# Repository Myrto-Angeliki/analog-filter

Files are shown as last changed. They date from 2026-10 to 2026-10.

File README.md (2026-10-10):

# Analog Front-End (AFE) Active Low-Pass Filter Module

A custom 2-layer printed circuit board (PCB) designed in KiCad for sensor signal conditioning in embedded hardware systems. This module combines a low-noise $3.3\text{V}$ Low-Dropout (LDO) power regulator with a 2nd-order active Sallen-Key low-pass filter ($f_c \approx 1.06\text{ kHz}$) and a unity-gain buffer stage to attenuate high-frequency noise prior to Analog-to-Digital Converter (ADC) sampling.

---

## Technical Specifications

* **Input Voltage ($V_{CC}$):** $5.0\text{V DC}$ nominal
* **Regulated Rail ($V_{DD}$):** $3.3\text{V DC}$ (AP2112K-3.3 LDO, up to $600\text{mA}$)
* **Filter Topology:** 2nd-Order Sallen-Key Low-Pass Filter + Output Voltage Follower Buffer
* **Characteristic Frequency ($f_c$):** $1.061\text{ kHz}$ ($-6\text{ dB}$)
* **Roll-off Rate:** $-40\text{ dB/decade}$
* **Active Components:** 
[MCP6002 Dual Rail-to-Rail CMOS Operational Amplifier (SOIC-8)](https://ww1.microchip.com/downloads/aemDocuments/documents/MSLD/ProductDocuments/DataSheets/MCP6001-1R-1U-2-4-1-MHz-Low-Power-Op-Amp-DS20001733L.pdf) , 
[AP2112K-3.3 LDO (SOT-23-5/SOT-25)](https://gr.mouser.com/datasheet/3/175/1/AP2112.pdf)
* **PCB Form Factor:** 2-Layer, $30\text{ mm} \times 40\text{ mm}$, hybrid SMT ICs with through-hole passives for rapid benchtop prototype assembly.

---

## Circuit Architecture & Calculations

### 1. Power Management & Decoupling
* **LDO Regulator:** AP2112K-3.3 steps down $5\text{V}$ $V_{CC}$ to a quiet $3.3\text{V}$ analog power rail.
* **Input/Output Capacitors:** $1\ \mu\text{F}$ MLCC on $V_{IN}$ and a $2.2\ \mu\text{F}$ MLCC on $V_{OUT}$. The $2.2\ \mu\text{F}$ value was selected over the $1\ \mu\text{F}$ minimum datasheet rating to account for ceramic DC-bias capacitance derating at $3.3\text{V}$ operating potential.
* **Local Decoupling:** A $100\text{ nF}$ ceramic capacitor is placed directly adjacent to the MCP6002 op-amp $V_{DD}$ pin (Pin 8) to mitigate high-frequency supply ripple.

### Sallen-Key Low-Pass Filter

The characteristic frequency ($f_0$) for the selected equal-component configuration ($R_1 = R_2 = 10\text{ k}\Omega$, $C_1 = C_2 = 15\text{ nF}$) is:

$$f_0 = \frac{1}{2\pi \sqrt{R_1 R_2 C_1 C_2}} \approx 1,061\text{ Hz}$$

Because $C_1 = C_2$, $R1 = R2$ and because tha operational amplifier is configured as a unity gain buffer (A = 1), the filter operates with $Q = 0.5$ (critically damped response):
* **Characteristic Frequency ($f_0$):** $1.061\text{ kHz}$ ($-6\text{ dB}$ attenuation)
* **Half-Power Cutoff Frequency ($f_{-3\text{dB}}$):** $\approx 683\text{ Hz}$ ($-3\text{ dB}$ attenuation)

### 3. Output Buffer
Op-Amp Channel B of MCP6002 is configured as a unity-gain voltage follower (connecting `OUTB` Pin 7 to `INB-` Pin 6). This presents a high input impedance to the filter stage and a low output drive impedance to downstream microcontrollers, eliminating loading effects on the filter's frequency response.

---

## LTspice Simulation

Prior to layout, the Sallen-Key low-pass filter was validated in LTspice using small-signal AC frequency analysis.

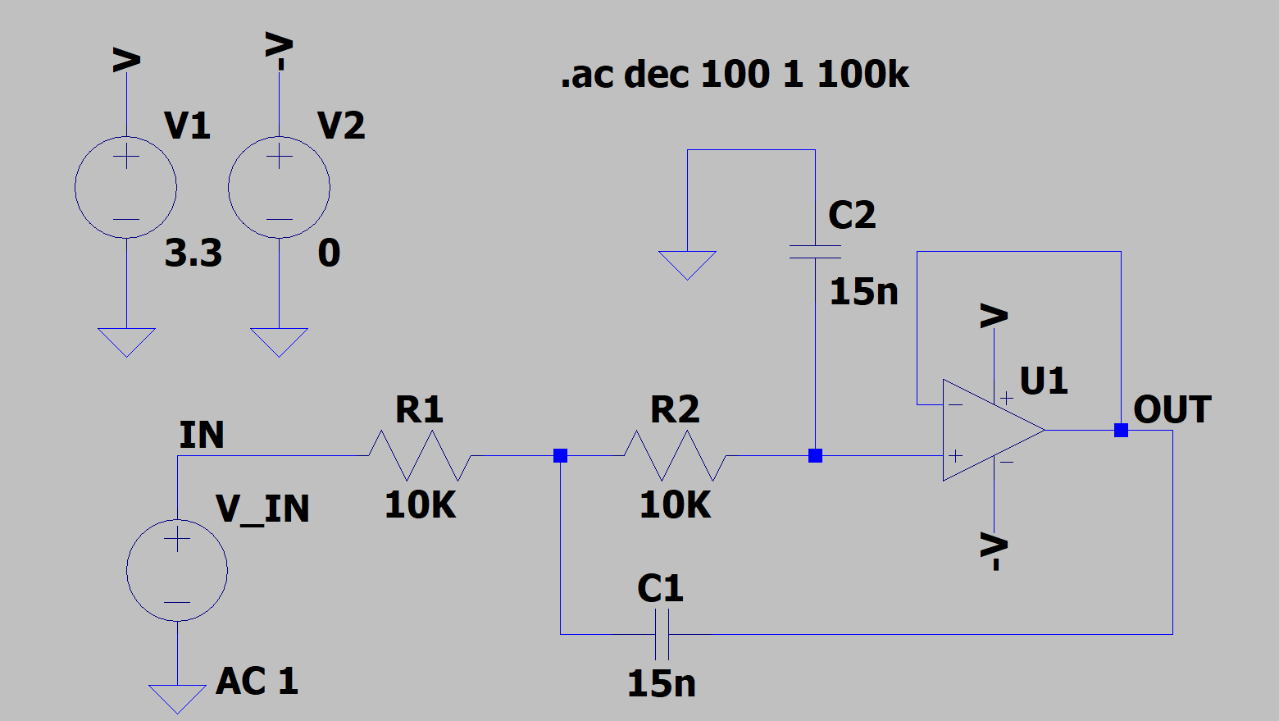
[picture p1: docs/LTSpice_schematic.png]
LTSpice_schematic


<br />

* **Simulation Directive:** `.ac dec 100 1 100k`
* **Passband Gain:** $0\text{ dB}$ up to $100\text{ Hz}$
* **$-6\text{ dB}$ frequency:** Verified at $\approx 1.06\text{ kHz}$
* **$-3\text{ dB}$ frequency:** Verified at $\approx 683\text{ Hz}$
* **Stopband Attenuation:** Confirmed $-40\text{ dB/decade}$ attenuation slope above cutoff frequency.

<table align="center">
    <thead>
        <tr>
            <th scope="col">Frequency at -3 dB</th>
            <th scope="col">Frequency at -6 dB</th>
            <th scope="col">Attenuation slope above cutoff frequency</th>
        </tr>
    </thead>
    <tbody> 
        <tr>
            <td>
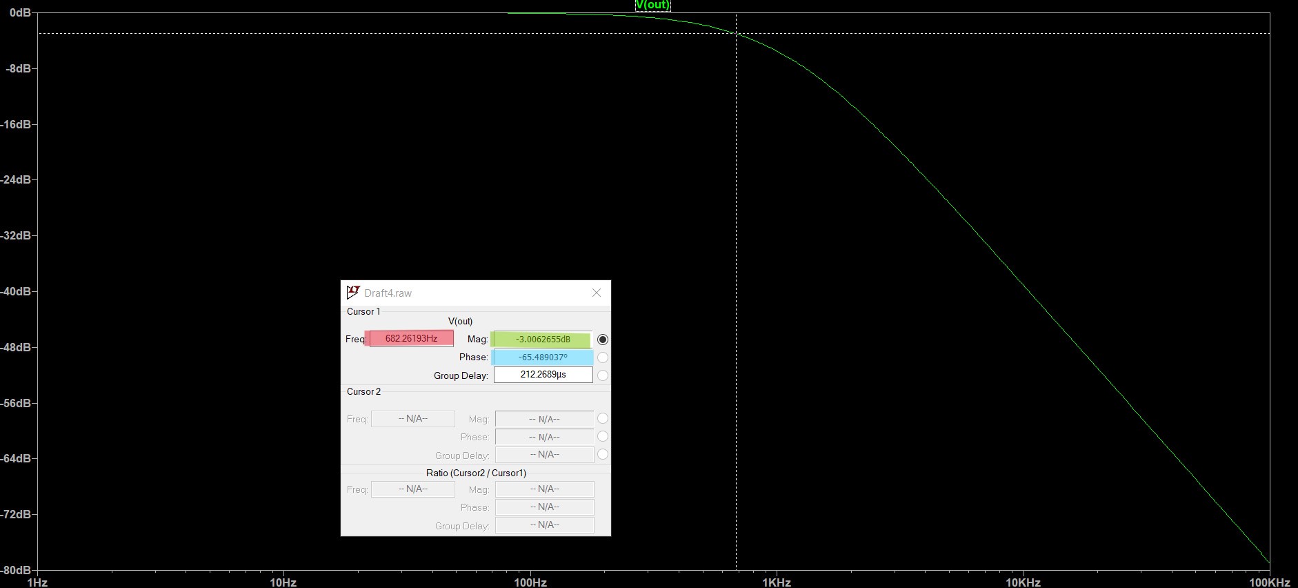
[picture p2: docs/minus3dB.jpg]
frequency-at-minus3dB
                 
            </td>
            <td>
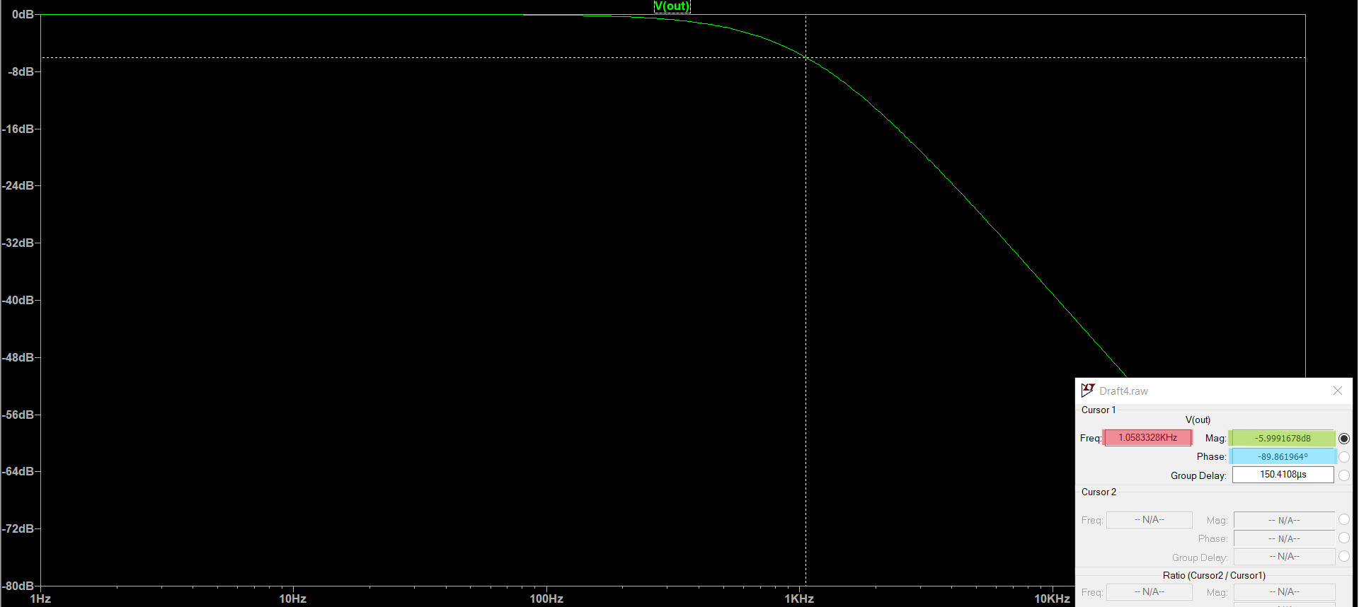
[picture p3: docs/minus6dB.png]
frequency-at-minus6dB
                
            </td>
            <td>
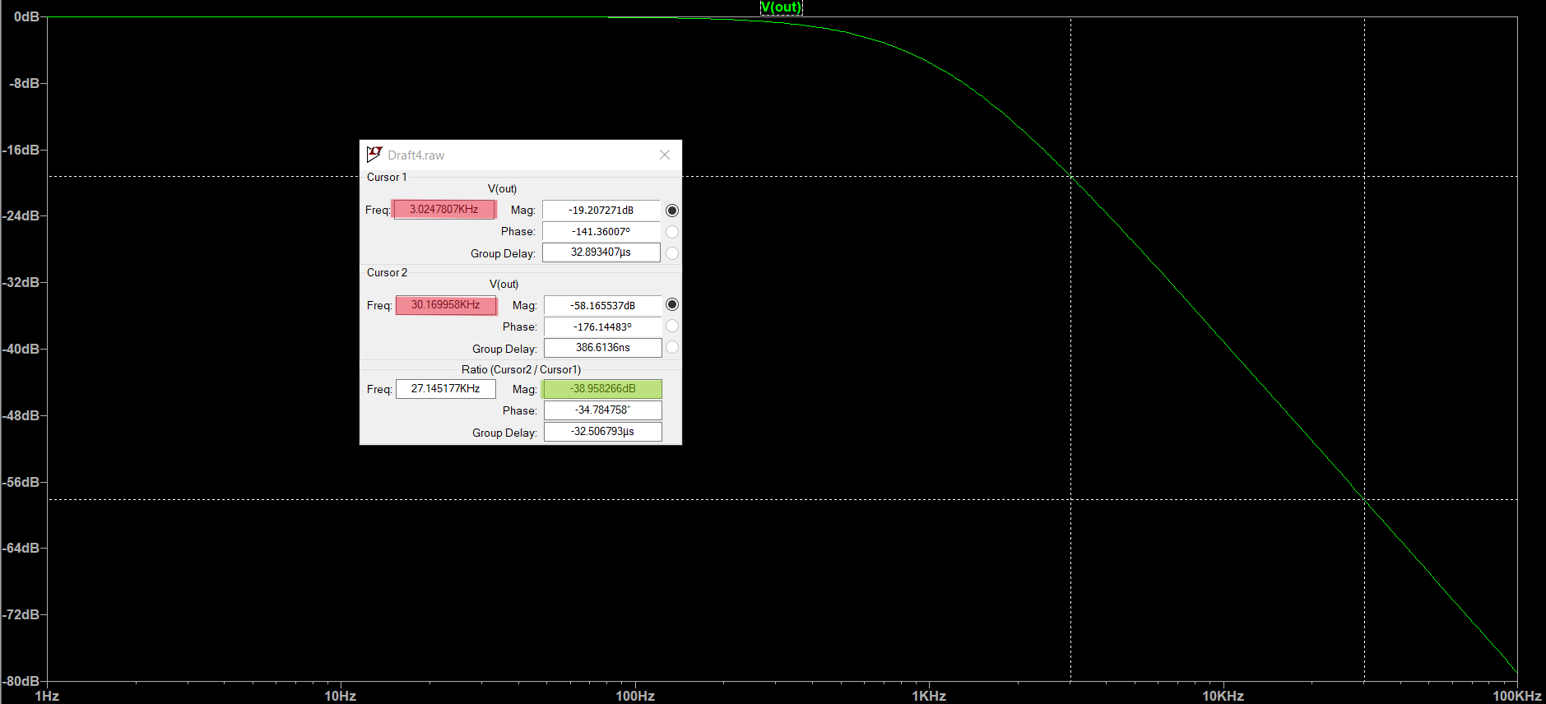
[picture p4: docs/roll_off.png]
attenuation-slope
                
            </td>
        </tr> 
    </tbody> 
</table>
<p align="center">
  <em>Measurings on the Bode plot output for the V(out) trace (Gain = 1).</em>
</p>

<br />

---

## Board Pinout & Interface

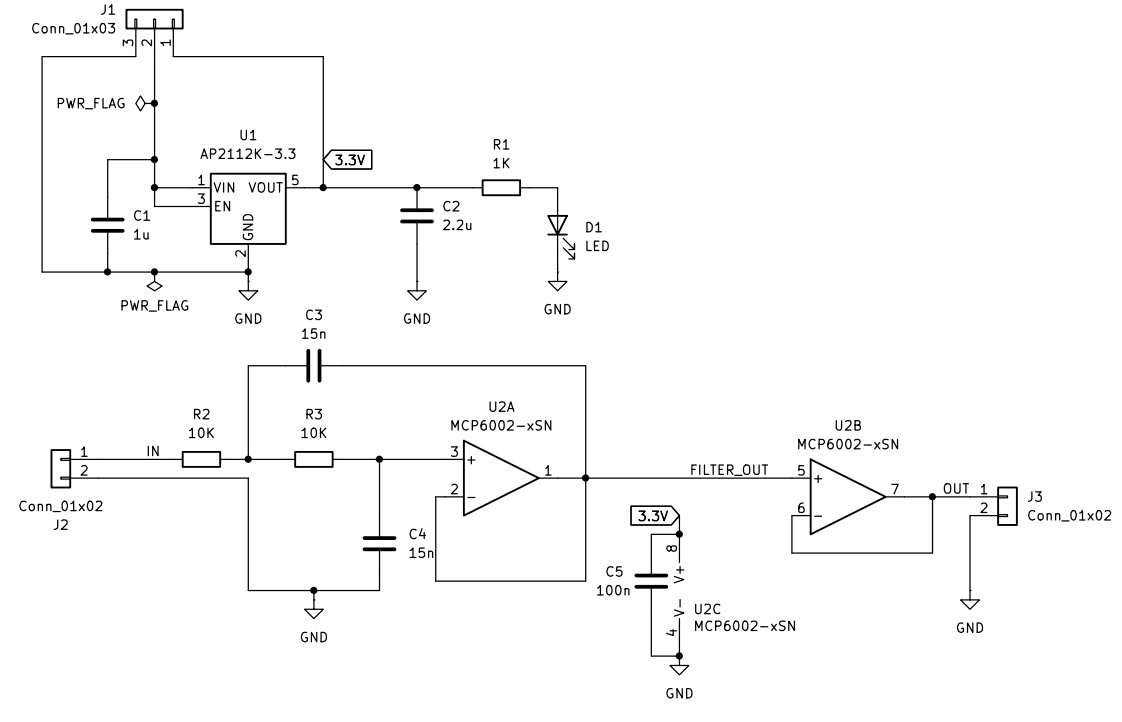
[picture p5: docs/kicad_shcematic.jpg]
KiCad_schematic


| Header | Pin | Name | Type | Description |
| :--- | :--- | :--- | :--- | :--- |
| **Power (J1)** | 1 | `3.3V` | Power | $+3.3\text{V}$ Regulated Output Rail |
| | 2 | `VCC` | Power | $+5.0\text{V}$ Unregulated Power Input |
| | 3 | `GND` | Power | Common System Ground Plane |
| **Input (J2)** | 1 | `IN` | Analog Input | Raw Signal Input from Sensor |
| | 2 | `GND` | Power | Signal Ground |
| **Output (J3)**| 1 | `OUT` | Analog Output| Conditioned & Buffered Signal to ADC |
| | 2 | `GND` | Power | Signal Ground |

---

## PCB Layout Considerations

<table align="center">
    <thead>
        <tr>
            <th scope="col">PCB Front 3D View with Visible Components</th>
            <th scope="col">PCB Back 3D View with Visible Components</th>
        </tr>
    </thead>
    <tbody> 
        <tr>
            <!-- <th scope="row"></th> -->
            <td>
                <a href="docs\analog_filter_modules_front_models.png"> 
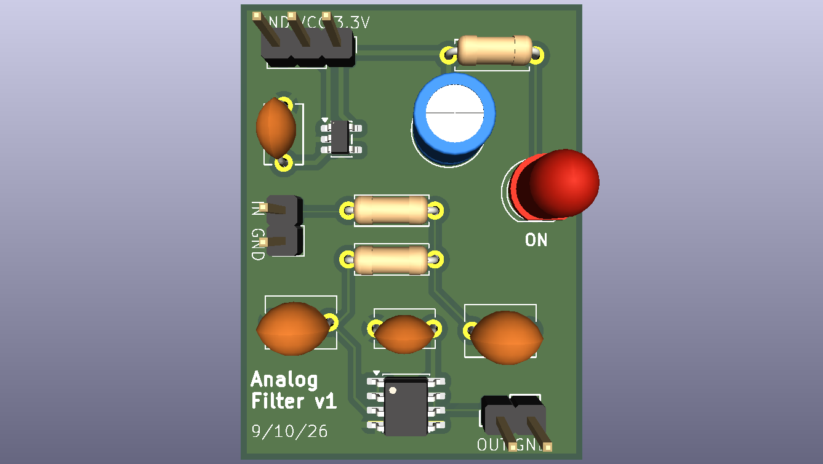
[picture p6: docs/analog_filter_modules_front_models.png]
pcd-front-with-modules
                     
                </a> 
            </td>
            <td>
                <a href="docs\analog_filter_modules_back_models.png"> 
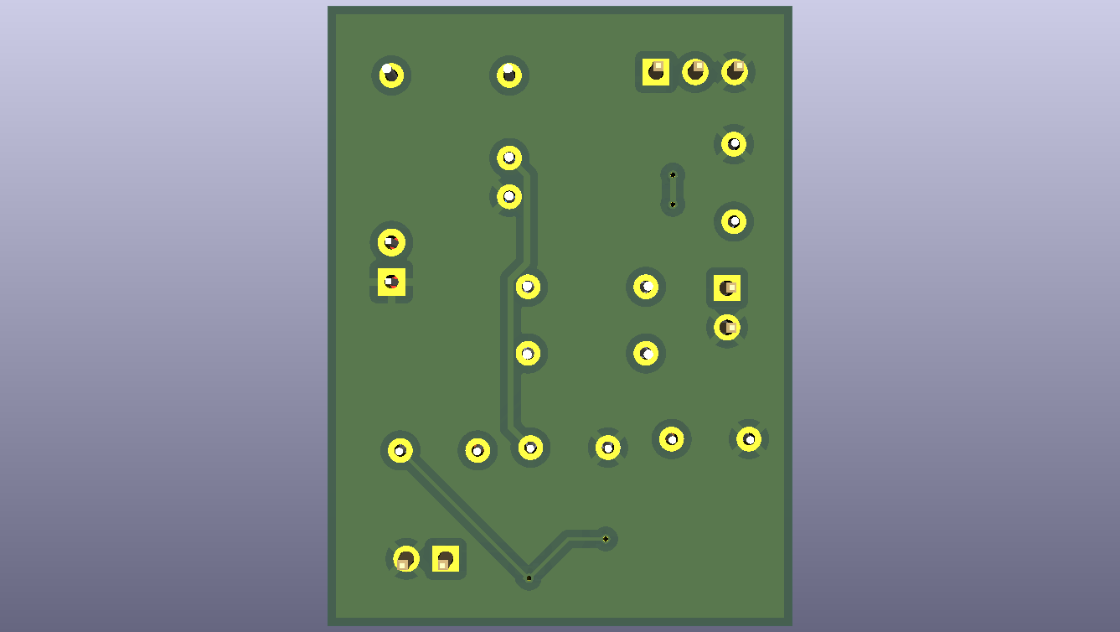
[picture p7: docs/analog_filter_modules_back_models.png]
pcd-back-with-modules
                      
                </a> 
            </td>
        </tr> 
        <tr>
            <th scope="col">PCB Front 3D View</th>
            <th scope="col">PCB Back 3D View</th>
        </tr>
        <tr>
            <td>
                <a href="docs\analog_filter_modules_front.png"> 
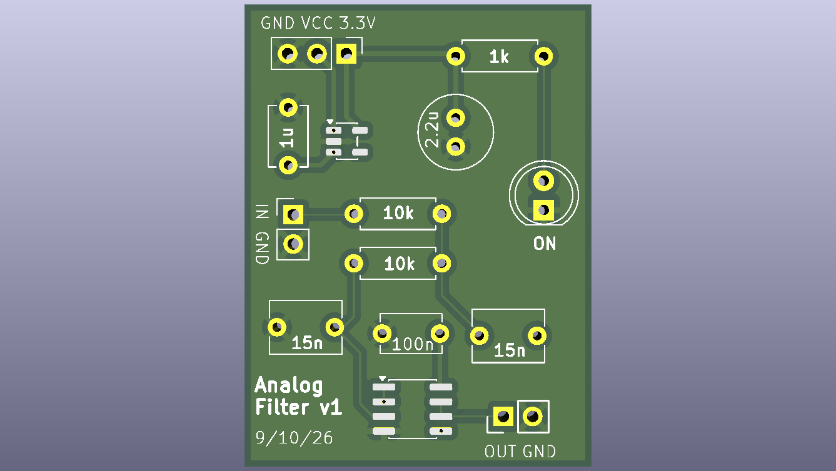
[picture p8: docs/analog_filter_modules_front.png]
pcd-front
                     
                </a> 
            </td>
            <td>
                <a href="docs\analog_filter_modules_back.png"> 
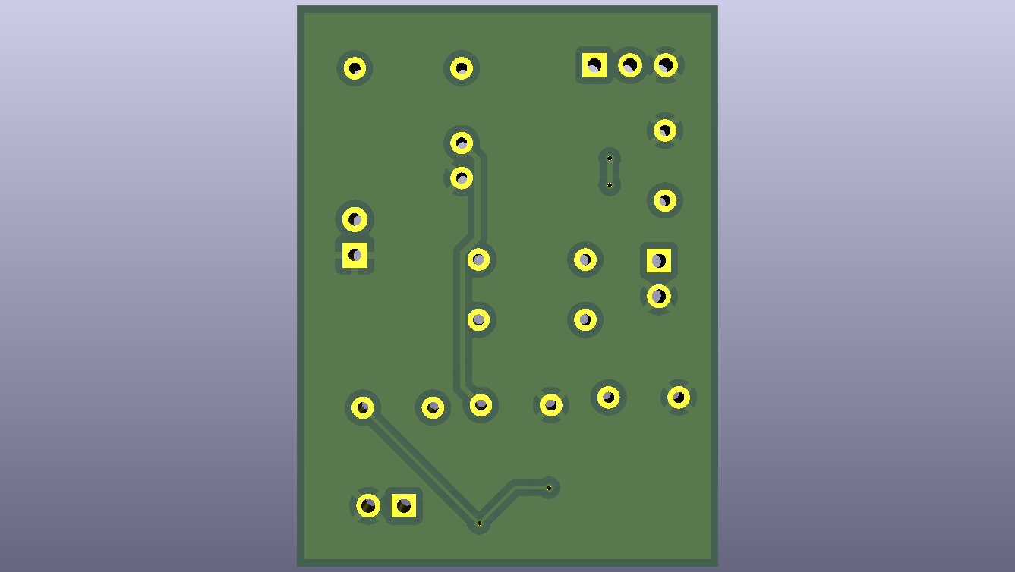
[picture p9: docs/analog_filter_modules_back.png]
pcd-back
                      
                </a> 
            </td>
        </tr> 
    </tbody> 
</table>
<p align="center">
  <em>3D Views of the PCB design.</em>
</p>

<br />

* **Ground Pour Strategy:** Top (`F.Cu`) and Bottom (`B.Cu`) layers are poured with continuous `GND` copper fills to provide a low-impedance ground return path and improve thermal dissipation.
* **Component Placement:** Power routing and decoupling components are placed close to the board headers and active supply pins to minimize current loop inductance.
* **Signal Isolation:** Analog input and output traces are routed with high clearance from power lines to reduce crosstalk and noise coupling.

---

## Repository Structure

```text
.
├── docs/                 # LTspice schematics, Bode plot outputs, PCB Views, BOM
├── gbr/                  # Production Gerber and Excellon drill files for PCB manufacturing
├── kicad/
│   ├── Analog_Filter.kicad_sch  # KiCad schematic design
│   ├── Analog_Filter.kicad_pcb  # PCB layout & routing
│   └── Analog_Filter.pro        # KiCad project file
└── README.md             # Project overview

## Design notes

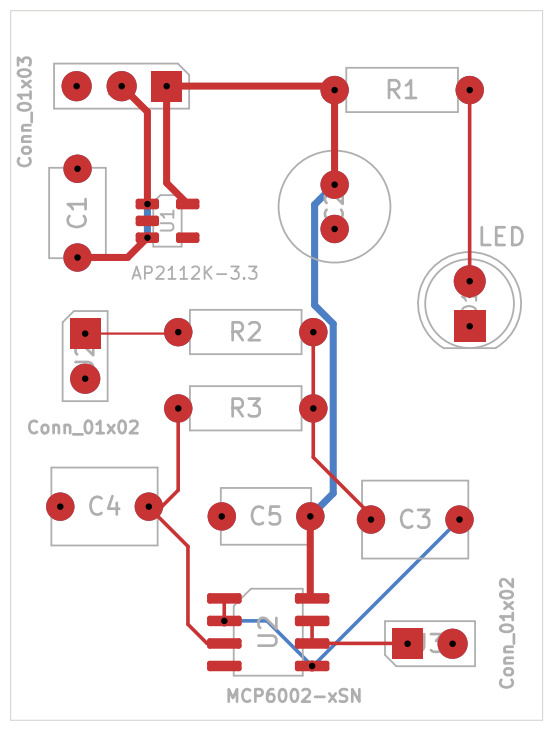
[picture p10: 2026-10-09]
docs/routes.jpg

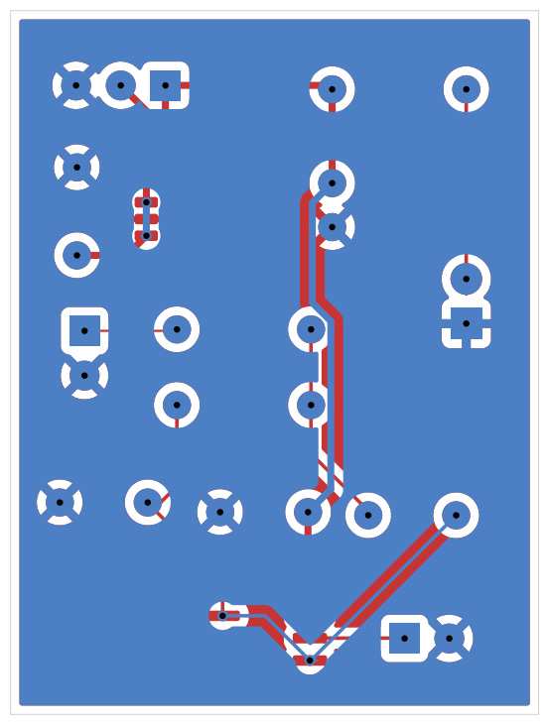
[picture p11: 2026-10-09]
docs/back_filled.jpg

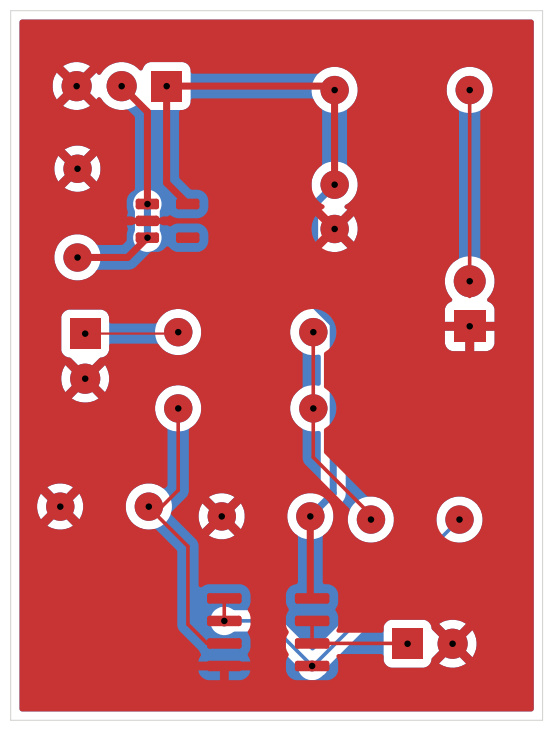
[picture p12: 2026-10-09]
docs/front_filled.jpg

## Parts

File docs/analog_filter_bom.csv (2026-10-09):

Reference | Qty | Value | DNP | Footprint | Datasheet
C1 | 1 | 1u |  | Capacitor_THT:C_Disc_D5.1mm_W3.2mm_P5.00mm
C2 | 1 | 2.2u |  | Capacitor_THT:C_Radial_D6.3mm_H7.0mm_P2.50mm
C3,C4 | 2 | 15n |  | Capacitor_THT:C_Disc_D6.0mm_W4.4mm_P5.00mm
C5 | 1 | 100n |  | Capacitor_THT:C_Disc_D5.1mm_W3.2mm_P5.00mm
D1 | 1 | LED |  | LED_THT:LED_D5.0mm
J1 | 1 | Conn_01x03 |  | Connector_PinHeader_2.54mm:PinHeader_1x03_P2.54mm_Vertical
J2,J3 | 2 | Conn_01x02 |  | Connector_PinHeader_2.54mm:PinHeader_1x02_P2.54mm_Vertical
R1 | 1 | 1K |  | Resistor_THT:R_Axial_DIN0207_L6.3mm_D2.5mm_P7.62mm_Horizontal
R2,R3 | 2 | 10K |  | Resistor_THT:R_Axial_DIN0207_L6.3mm_D2.5mm_P7.62mm_Horizontal
U1 | 1 | AP2112K-3.3 |  | Package_TO_SOT_SMD:SOT-23-5 | https://www.diodes.com/assets/Datasheets/AP2112.pdf
U2 | 1 | MCP6002-xSN |  | Package_SO:SOIC-8_3.9x4.9mm_P1.27mm | http://ww1.microchip.com/downloads/en/DeviceDoc/21733j.pdf

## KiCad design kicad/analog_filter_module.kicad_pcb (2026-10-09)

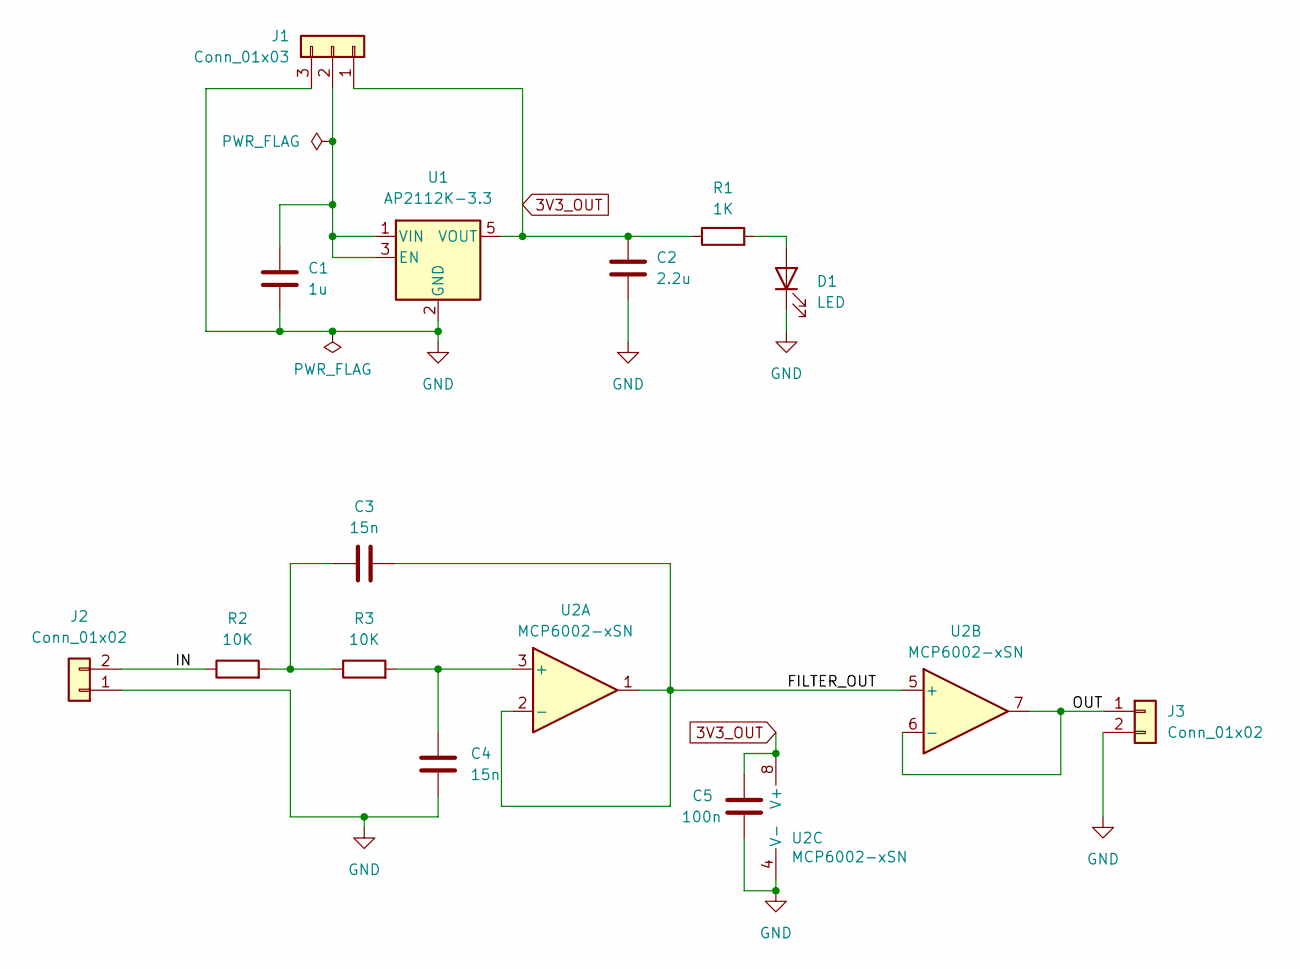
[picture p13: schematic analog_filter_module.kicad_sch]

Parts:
C1: 1u; C_Disc_D5.1mm_W3.2mm_P5.00mm
C2: 2.2u; C_Radial_D6.3mm_H7.0mm_P2.50mm
C3, C4: 15n; C_Disc_D6.0mm_W4.4mm_P5.00mm
C5: 100n; C_Disc_D5.1mm_W3.2mm_P5.00mm
D1: LED; LED_D5.0mm
J1: Conn_01x03; PinHeader_1x03_P2.54mm_Vertical
J2, J3: Conn_01x02; PinHeader_1x02_P2.54mm_Vertical
R1: 1K; R_Axial_DIN0207_L6.3mm_D2.5mm_P7.62mm_Horizontal
R2, R3: 10K; R_Axial_DIN0207_L6.3mm_D2.5mm_P7.62mm_Horizontal
U1: AP2112K-3.3; SOT-23-5
U2: MCP6002-xSN; SOIC-8_3.9x4.9mm_P1.27mm

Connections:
3V3_OUT: C2.1, C5.1, J1.1, R1.1, U1.5 (VOUT), U2.8 (V+)
/FILTER_OUT: C3.2, U2.1, U2.2 (-), U2.5 (+)
/IN: J2.2, R2.1
/OUT: J3.1, U2.6 (-), U2.7
GND: C1.2, C2.2, C4.2, C5.2, D1.1 (K), J1.3, J2.1, J3.2, U1.2 (GND), U2.4 (V-)
unnamed: C3.1, R2.2, R3.1
unnamed: D1.2 (A), R1.2
unnamed: C1.1, J1.2, U1.1 (VIN), U1.3 (EN)
unnamed: C4.1, R3.2, U2.3 (+)

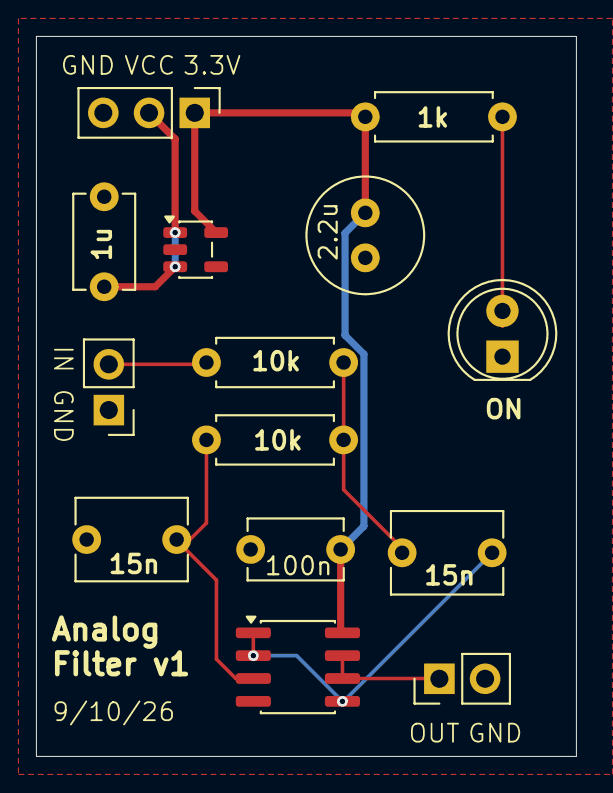
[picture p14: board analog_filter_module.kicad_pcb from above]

Board: 4 copper layers, 30.0 x 40.0 mm, 14 parts (0 on the bottom side), 9 nets.
